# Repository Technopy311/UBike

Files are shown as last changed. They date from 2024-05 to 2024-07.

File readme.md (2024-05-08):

# UBike IWG101 Project

## Brief description

This project created for Introduction to Engineering (IWG101), consists in the research and consequently development 
of an automated bicycle holder, this with the purpose of optimizing the saving process of a bicycle in the university.

## Technologies involved

### Software

Web:
- Django Framework (Backend)
- Bootstrap Library (Frontend)

Hardware:
- ESP32 C++/Arduino custom code.

### Hardware

- ESP32 Dev Kit 1, as microcontroller.
- RFID reader module (RC522).
- Red LED.
- Custom primary security system.
- Relay.
- Solenoid.

### Primary security system
Each module will have a security system, wich will activate in cases such:
- Improper module handling.
- Energy outage.
- Robbery attempt.

Under this events, this system will become active, this prevents the unlocking of the solenoide, unless a designated manager solves the conflict or issue

## Working process:
- A series of modules will be available, each one in a parking site.
- All the modules will connect through WiFi, to a centralized server, which will be in charge of managing the authentication, permissions, registering, among others.
- The authentication will be made through the Unique ID of each keychain (provided to each user, per bicycle).
- Once authenticated (and server-side confirmed), the solenoid will contract for a few seconds, allowing the user to save the bicycle.
- It is necessary perform the authentication to either save or take out the bicycle, this with the objective to improve security and backup records.
- The LED will indicate through blinking, the status of the solenoid.

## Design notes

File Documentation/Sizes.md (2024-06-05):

# Device sizes
## ESP32 Dev-Kit
54.6mm x 27.49mm
## RC522 (RFID reader)
59.5mm x 39mm
## Step-Down module
48.5mm x 23mm
## Relay coil
40mm x 15mm x 20mm
## Case
120mm x 77mm x 37mm

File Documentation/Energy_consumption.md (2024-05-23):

# uBike module power consumption
## Power Supply
To provide electricity to every module, we are currently using a Huawei branded Modem power supply, which suplies 12 volts at 1.5 amperes (maximum 18 watt per hour)

The current must be divided in 2 ways, one will pass through a Step-Down module (LM2596) to lower the voltage that will reach the central module, the other shall get cut at the Relay module, which will only keep that current going when the central module send the signal to the relay module.
## ESP32 Energy consumption and power output
The ESP32 DevKit ofers up to 3.3 volts at 40 mAmps (20 recomended) per gpio Pin
## Energy consumption sheet
- Led (Single) = 47 mAmps at 3.3 volts (Without resistor) = 150 mOhms
- RGB Led (White) = 80 mApms divided in 3 pins at 3.3 volts
- RGB Led (White, 16 ohm Resistor added) = 30 mAmps divided in 3 pins at 3.3 volts
- Buzzer = 15 mApms at 3.3 volts = 50 mOhms
- RC522 = 6 mAmps at 3.3 volts (On standby)
- Relay = 1.5 mAmp at 3.3 volt (On standby)
## Single Module consumption
A single module in neutral state (Waiting for a keychain) needs at least 200 mAmps to work correctly.
## Solenoid device consumption
The device that is used to lock the bikes uses almost the whole capacity of the power supply, hence, the resistance of the solenoid is 8 ohms, because of that, the circuit board of the module must contain electrolytic Capacitors, to hold the power while the solenoid circuit is closed.
- The solenoid doesn't need to be powered for more than half a second, that time is just enough to unlock the bike.

## Conclusion
The power supply we are currently using is enough to power multiple modules at once, however we will focus in make a single one working from it.

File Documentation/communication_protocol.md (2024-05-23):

# Communication Protocol between Server and ESP32 module

## Description
This document describes verbally how is established the communication 
through HTTP between the main Server and the ESP32 module, how it behaves
and the primitive protocol that has been created to allow this nexus.

### The concept

In first place, it is necessary to have in mind that this protocol has been
designed for a simple thing as objective, and it is to:

<ol> 
    <li>Allow the ESP32 module send the authentication data it gathers from the User's physical RFID Keychain, identify itself, and get the response back from the server.</li>
    <li>Allow the server tell the ESP32 if it needs to open a slot to permit the saving or remotion of bicycles if needed or pertinent.</li>
</ol>

Issues related to security will not be addressed by now, since it has been left for the last stage of the project, and could even not be included for the final delivery.

### First part: From ESP32 to the Server.

In this project, we have got to the necessity of identifying each user, so that way we can keep 
track of his bicycle and know his identity.

For such, we have decided to utilize a simple RFID Keychain. 
Why RFID? because it is very easy to implement this protocol in the ESP32 and other boards, through the use of libraries. 

In this consists the first step of the communication: Reading the Unique Identifier of the user's Keychain.
After performing such read, we save the value of it.

Now comes the second step, sending the data, to accomplish it, we first have to connect the board to Wifi, but that item is not covered in this documment; going forward and assuming Wifi connection, the board proceeds to create an HTTP POST request, an HTTP request is a petition to a web server, just like when a normal everyday user surfs the net, whenever this user wants to access a page (by clicking a link for example), the computer has to perform a request. The usual request, is to get something from the web server, and this kind of request is known as a GET request, but in this case, it is necessary to send data to the server, that is why the ESP32 has to perform a POST request. The HTTP communication is performed by already available libraries. 

For the POST request, there are a few things needed:
- URL: The "link" of the web server.
- UUID: The Unique Identifier of the Keychain.
- IP Address of the board.

This three elements allow us to start a connection to the server, by sending this data in a JSON format arbitrary set up by us (the developers). JSON you may ask, is a text format, which makes easy to standarize the access to information, you may think of it as a standard which allows you to say "Hey, I want the data to be in this order, and so on"

In this case, the JSON data we send, looks like this:
```{ "uuid": UUID OF THE KEYCHAIN, "ip": IP ADDRESS OF THE BOARD}```

That way, when receiving the data in the server, the server can inmediatly check the data with the name 'uuid' and 'ip', and access such elements.

### Second part: In the Server.

Assuming the request sent from the board has succesfully arrived at the web server, the server can now do things with this request, for the project's purposes, it is first mandatory to check if the data is the right data.

For this, we first make sure that the request is a POST request, if it isn't, we throw it away.
Then, we make sure that the JSON data (as show before) exists, and has the information we need, else we throw it away.

After this, we can perform a second step, the most important one, use the data!

#### Using the data

The flow is as follows:

<ol>
    <li>Check if the UUID is an integer value.</li>
    <li>Get the Keychain with such UUID from the Database (DB).</li>
    <li>Get the ESP32 module with the same IP Address from the DB.</li>
    <li>Access the Bicycle Holder associated with the ESP32 module.</li>
    <li>Access the user related to the Keychain.</li>
    <li>Try to get the user's Bicycle.</li>
    <li>Check if the Bicycle is in the Bicycle Holder.</li>
    <li>If the Bicycle is not in the Holder, check if its in another holder.</li>
    <li>If the Bicycle is not in another holder, add it to the Bicycle holder</li>
    <li>If the Bicycle is in the holder, then remove it from it.</li>
</ol>

Each time any step in this sequence fails, the server sends a response to the ESP32 telling it that it
failed... Well... almost.

In the steps 8, 9 and 10, the server sends some special responses to the board, allowing it to know that this
special cases have ocurred.

### Second part, part 2?: From the Server to the ESP32:

Keeping with the idea of the special cases, we have aggreed to create a special language to communicate and let know the board what has happened.

Since this is programming, we have chosen to use a tuple to make easier this task, it is like this "(elem1, elem2, elem3, ..., elemN)"

Why? Because once created you can't change them, this prevents from errors happening while the server is running; and because it is intuitive the way to access the data in them, like a list. For more details, use google.

The format for the tuple we use, is like so: ```(code, index_slot)```

The code, is the element which allows the board to know what situation has happened; and the index_slot is the number of slot that the ESP32 has to open.

This are the situations that could happen, and the tuple created for the case:

- Bicycle is in another holder: ("-1", None)
- Bicycle added to holder: ("0.1", slot_position)
- Bicycle is not a real bicycle: ("0.2", None)
- There is no empty place: ("0.3", None)
- Bicycle removed from holder: ("1.1", slot_position)
- Bicycle not in holder: ("1.2", None)

After this, we take the tuple data, and we give it to a JSON object which looks like so:
```
    {
      "code": controller_data[0],
      "slot_to_open": controller_data[1]
    }
```

In the "code" part, we put the first item of the tuple, and in the "slot_to_open" we put the second item of the tuple.

Then we send an HTTP response to the ESP32 Board, with the data, and a HTTP status code of 200, which lets know the ESP32 know that the connection has been successful.

### Third and last part: Back in the ESP32.

This element has not yet coded, but it is very trivial, something to be done after finishing tests in the communication, to make sure it works smoothly, fast and very robust.

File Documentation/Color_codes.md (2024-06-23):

# Color codes for each case
- Neutral (Free) :  
    >Green: #00FF00 HEX or (0,1,0) RGB
- Neutral (Ocupied) : 
    >Blue: #FFFFFF HEX or (0,0,1) RGB
- Reading / Processing : 
    >Cyan: #00FFFF HEX or (0,1,1) RGB
- Process error or invalid RFID tag : 
    >Magenta: #FF00FF HEX or (1,0,1) RGB
- Wrong parking : 
    >Yellow: #FFFF00 HEX or (1,1,0) RGB
- Accepted / Authenticated / Starting machine :  
    >White: #FFFFFF HEX or (1,1,1) RGB
- Emergency mode / Error in the machine : 
    >Red: #FF0000 HEX or (1,0,0) RGB

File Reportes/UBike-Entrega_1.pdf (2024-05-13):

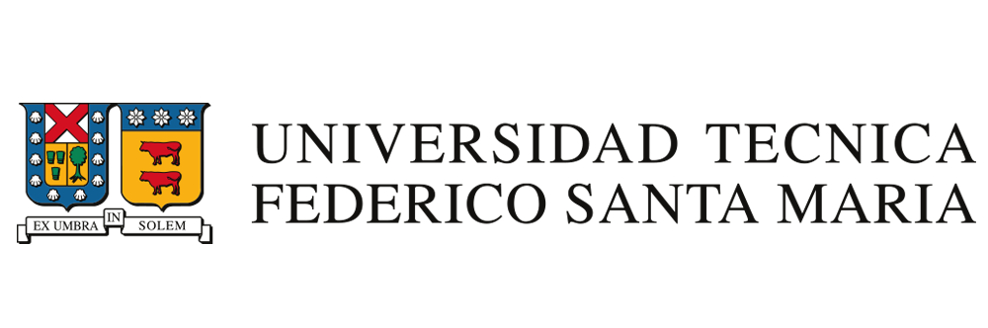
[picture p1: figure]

IWG101: Introduccion A La Ingenier ´ | ía

## Primera Entrega Proyecto UBike - Introducción a la Ingeniería

Estudiantes: | Sebastián Saldías - Acza Riffo - María Poblete - Josué Leiva
Profesor: | Luis Lizama
Ayudante: | Andrés Pino
Fecha: | 08 de Mayo, 2024

## Contents

1 Resumen | 2
2 Introducción | 2
3 Desarrollo | 2
4 Diagramas | 4
5 Conclusiones | 7
6 Referencias | 7

IWG101 Introducción a La Ingeniería | 2024

## 1 Resumen

En esta entrega del proyecto UBike —University Bike—, se presentarán diversos aspectos, se detallará la problemática que solucionaremos y por sobre todo se ahondará en el método de solución que estamos utilizando. Junto a esto se presenta un poco de la planificación y las tareas que estamos próximas a completar. Complementamos esta información con algunos diagramas que ilustran los procesos más técnicos.

## 2 Introducción

En esta primera entrega, se abordarán diversas problemáticas con respecto al proyecto llamado UBike. Se tratarán elementos tales como la planificación del proyecto, sus áreas, y el método de solución de la problemática. Esto además de presentar los avances ya existentes, en progreso y por realizar; incluída una calendarización con fechas estimadas.
Recordando un poco, se tiene que el problema a analizar, e idealmente resolver de manera inicial, trata (en pocas palabras) de abordar el dilema de la inseguridad e ineficiencia en cuanto al uso de los bicicleteros en las instalaciones de la universidad.

## 3 Desarrollo

### 3.1 Método de Resolución

Para resolver este problema, junto al equipo, se pensó en crear un sistema que permita al estudiantado utilizar algún medio de autenticación para así poder ingresar y en su defecto, retirar, la bicicleta que el mismo utilice en la USM.
Abordando la idea, se ideó utilizar alguna tarjeta o llavero con tecnología RFID para la autenticación y algún tipo de módulo que permita leer este objeto, y que pueda enviar esta información a algún servidor para ser procesada. Este dicho módulo, se encontraría en cada bicicletero, permitiendo así que cada uno de estos, fuese independiente de otro, tanto en energía como en libertad de locación.
Luego de discutirlo, se decidió proseguir de la siguiente manera: Utilizar un microcontrolador Raspberry Pi Pico W [1] como dispositivo central del módulo, una tarjeta lectora de RFID [2] modelo RC522 [3] la cual se conectaría a este microcontrolador, un diodo LED de color rojo para efectos de indicar el funcionamiento del módulo. Se escogió utilizar este microcontrolador inicialmente, ya que permite conectividad Wifi y Bluetooth, lo que nos otorga flexibilidad para desarrollar esta solución.
La tarjeta lectora se conectaría a este microcontrolador, al igual que el LED, mediante cables, hacia los puertos GPIO [4] de este. Este microcontrolador permite ser programado oficialmente mediante el soporte de micropython entregado por Raspberry Pi Foundation, o mediante un SDK de C/C++ también soportado por la misma institución [5], para mayor facilidad se optó por el uso de micropython para programar el dispositivo.
Para poder procesar los datos y realizar procesos más exigentes, además de favorecer la escalabilidad, se decidió por establecer un servidor centralizado, en donde cada módulo (por cada bicicletero) se conecte mediante Wifi a este servidor, y pudiesen comunicarse para que así cada módulo pueda enviar el Unique ID (UID) de cada llavero o tarjeta (dato leído por la tarjeta RFID), hacia este servidor.
Con el fin de crear este servidor, se decidió desarrollar una página web mediante el robusto framework Django [6] de desarrollo backend, esto permite crear un backend robusto y rápido, fácilmente desplegable, además de seguro. Al tratarse de una plataforma web, se facilita tanto la comunicación módulo-servidor mediante la creación de APIs, como el acceso del usuario a la solución que se está planteando mediante una interfaz web.
Django es útil como solución backend, pero es necesario también una solución frontend, por simplicidad y agilidad, se utilizará la famosa librería de desarrollo BootStrap [7] la cual permite el desarrollo responsive de páginas web.
Antes de continuar, se presenta un diagrama esencial el cual tiene como finalidad sintetizar las ideas de este proyecto. No tiene como aspecto principal lograr precisión técnica, sino ilustrar un inicio del proyecto.
USM 2024 - 2 | 2

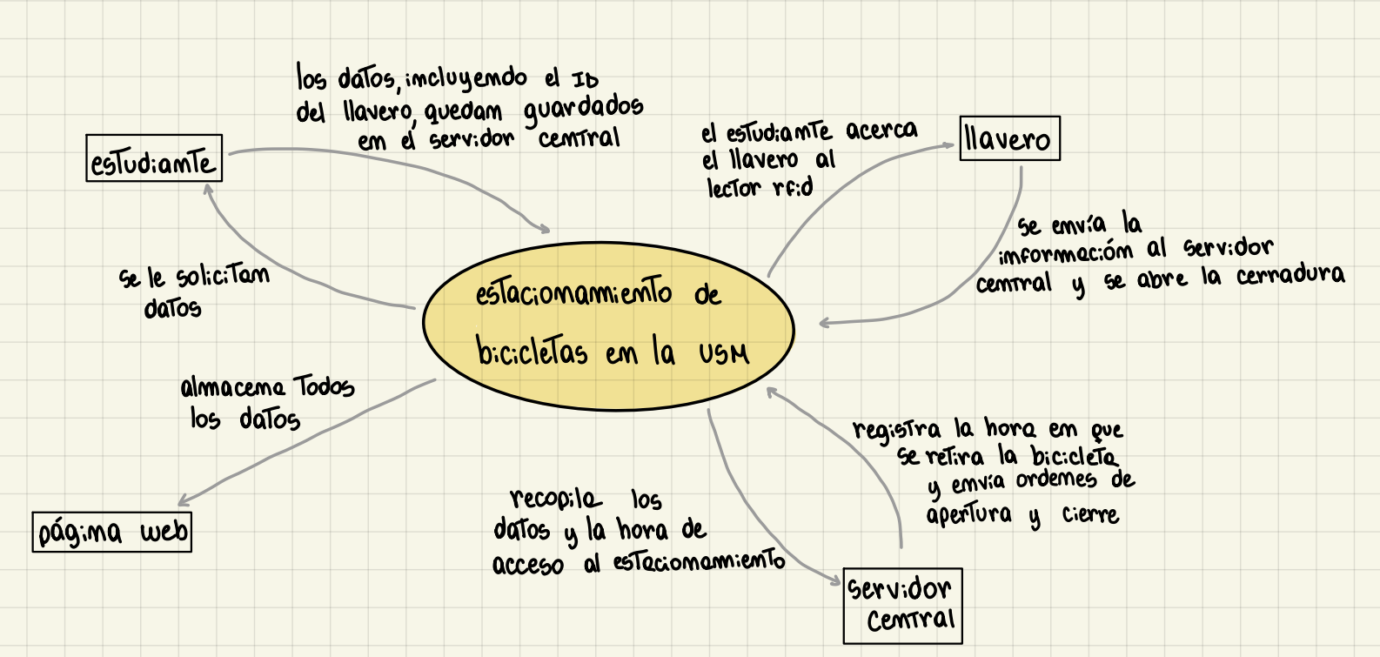
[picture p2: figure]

Figura. 1: Diagrama esencial del proyecto.

### 3.2 Cambios en el método

Lo visto en el ítem anterior es un desarrollo de la idea inicial, pero en vista del rápido avance necesario para cumplir con los plazos (más información posteriormente), este desarollo afectó a algunos cambios. El más notorio de estos, el cambio de microcontrolador.
Anteriormente se propuso utilizar el microcontrolador Raspberry Pi Pico W, pero se encontraron algunas limitaciones en el uso de este, algunas de estas siendo:
- Lentitud de ejecución de código.
- Falta de documentación robusta (micropython y SDK C/C++).
- Poca madurez en el desarrollo con micropython.

Para enfrentar este problema, se decidió cambiar el microcontrolador, esta vez utilizando la famosa placa de la compañía Espressif, en particular se trata de una ESP32 DevKit v1. [8] (o también llamado DevKitC).
Este microcontrolador es altamente utilizado en la industria, es robusto y tiene alta compatibilidad con diversidad de sistemas, librerias, protocolos, etc. También posee conectividad Wifi y Bluetooth, permitiendo al proyecto no desviar su curso en cuanto al desarrollo de software se trata, con una pequeña excepción.
Esta placa, se desarrolla utilizando C++, tal y como Espressif lo indica en su documentación [8], pero también se puede programar utilizando el famoso IDE de Arduino [9], lo cual facilita la tarea.
Cabe destacar que todo el avance, en cuanto a software se trata, se encuentra disponible en el repositorio de GitHub del proyecto UBike [10].

### 3.3 Planificación

Con el propósito de facilitar el avance, el proyecto se ha dividido en diversas áreas, en donde cada uno de los estudiantes del grupo trabaja, aprende y se especializa, esta son:

- Desarrollo Frontend (María Poblete, Acza Riffo)
- Modelación 3D (Sebastián Saldías)
- Electrónica (Sebastián Saldías)
- Desarrollo Embebido (Josué Leiva)
- Desarrollo Backend (Josué Leiva)

Como plataforma de organización en cuanto a tareas, avances y fechas se trata, se utiliza Microsoft Planner [11], una aplicación que permite el ordenamiento de los proyectos mediante la metodología Kanban.

Debido a la complejidad de la planificación, y a las limitaciones de la plataforma, en caso de desear obtener acceso a esta, favor enviar un correo solicitando este acceso a la siguiente dirección: jleivap@usm.cl. El equipo se reserva el derecho y libertad de autorizar a quien considere competente, el acceso a la plataforma.
A modo de resumen se pueden mencionar las siguientes tareas por realizar o completar:
- Entrega Nro. 1.
- Definir fuente de poder para prototipo.
- Definir material y diseño para soporte prototipo de bicicletas.
- Crear vistas de usuario (registro y común) (frontend).
- Crear vista para guardias (frontend).
- Implementar apertura de solenoide según Response de API.
- Realizar diagrama de cascada de los puntos críticos del proyecto.

Si bien existen más tareas por mencionar, se recalca nuevamente el uso de la plataforma Ms. Planner.

## 4 Diagramas

En este proyecto de alta complejidad, teniendo en cuenta de que se trata de un ramo de primer semestre, se destaca la importancia de entender conceptualmente el funcionamiento de la solución a desarrollar. En este punto es útil el uso y creación de diagramas de flujo, es por ello que se facilitan dos diagramas en particular, un primer diagrama de flujo que indica la lógica de funcionamiento del sistema, y un segundo diagrama que muestra el proceso de comunicación entre el módulo bicicletero y la API del servidor, esto mediante el protocolo HTTP y el uso de Wifi; figuras 2 y 3 respectivamente.

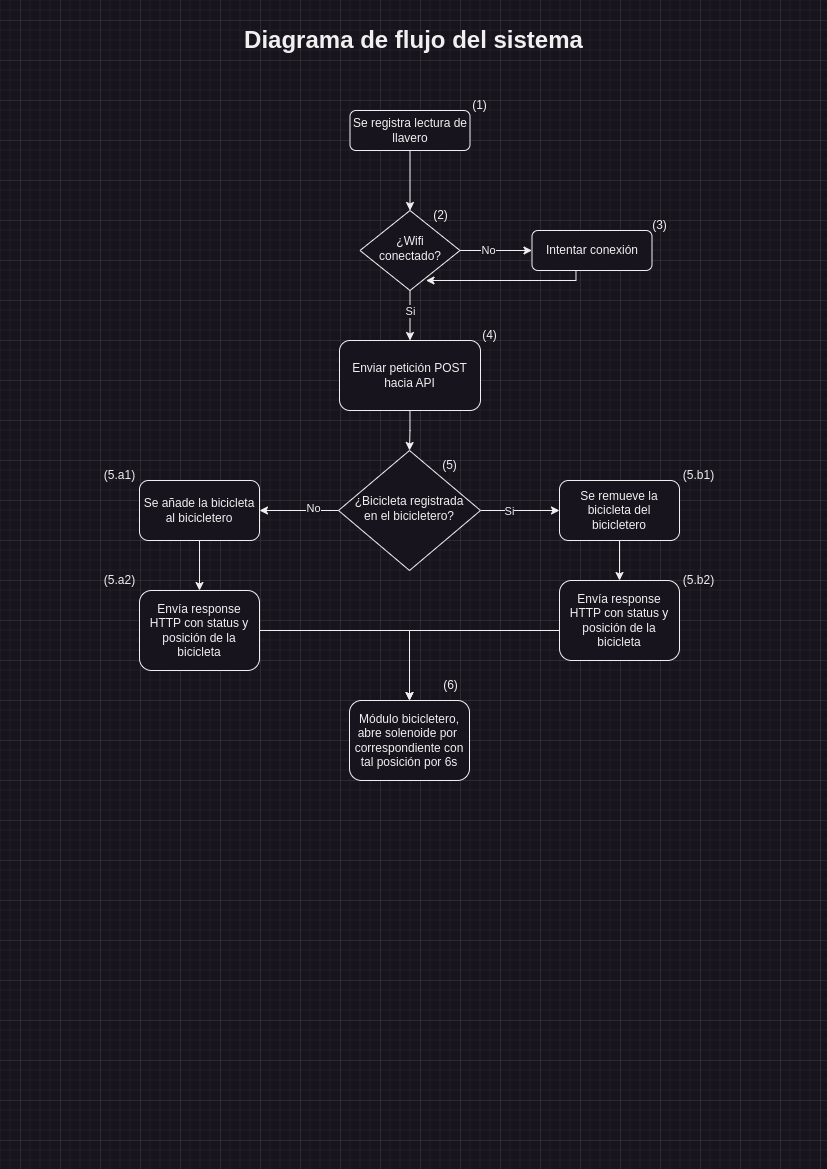
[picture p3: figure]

Figura. 2: Diagrama de flujo de lógica del funcionamiento.

Este diagrama de flujo, representa la lógica que nuestra solución plantea, brindando así una clara referencia con respecto a los objetivos que cada pieza de nuestro planteamiento, debe lograr.
El evento principal, el cual gatilla la lógica descrita, es la lectura del llavero del usuario, mediante el lector RFID ya mencionado anteriormente; y termina cuando el módulo finaliza la conexión con el servidor central y actua con respecto a la respuesta de este.

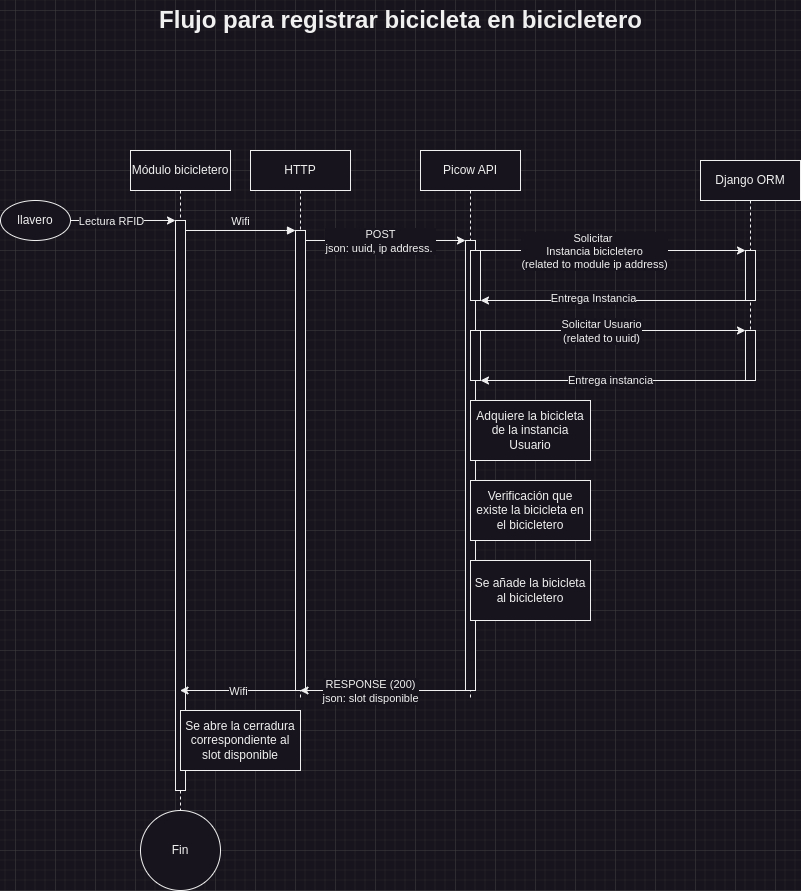
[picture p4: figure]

Figura. 3: Flujo de comunicación entre módulo bicicletero y servidor.

Esta última figura (diagrama de cascada), muestra el proceso de comunicación entre el módulo bicicletero y el servidor central, mediante el protocolo HTTP, utilizando WiFi de por medio.
A medida que avanza el proyecto, estas estructuras pueden variar, por lo que estos diagramas no son definitivos. Para esta entrega estos elementos sólo tienen la finalidad de ilustrar al lector cómo se está desarrollando esta solución.

### 4.0.1 Nota

Cabe destacar que hemos decidido no incluir en esta entrega algunos otros detalles de la solución. Entre estos elementos se incluyen: Método de seguridad primaria, planificación respecto al frontend y la lógica del sistema cuando ocurren excepciones en el funcionamiento de los distintos puntos críticos de la infraestructura digital que se está desarrollando.
Esto se ha decidido así, ya que creemos fundamental sentar bases robustas dentro del proyecto, para así no tener mayores problemas más adelante en el transcurso del desarrollo.

## 5 Conclusiones

Luego de presentar esta información, concluimos como equipo, en que es imperativo trabajar activamente entre integrantes, compartiendo información con las otras áreas, para así mantener un trabajo uniforme, que logre mantener la visión y objetivo de la solución a implementar.
Además de esto, reconocemos la necesidad de mantener una organización y estructuras claras, creando objetivos tanto a corto como a largo plazo, logrando así los avances necesarios para evitar retrasos.

## 6 Referencias

[1] R. P. Foundation, “Raspberry pi pico,” Disponible en https://www.raspberrypi.com/products/raspberry-pi-pico/.
[2] B. Fennani, H. Hamam, and A. O. Dahmane, “Rfid overview,” in ICM 2011 Proceeding, 2011, pp. 1–5.
[3] NXP, | “Mfrc522 | standard | performance | mifare | and | ntag | frontend,” | Disponible | en
https://www.nxp.com/docs/en/data-sheet/MFRC522.pdf (2024/04/4).
[4] R. | P. | Foundation, | “Physical | computing | with | python,” | Disponible | en
https://projects.raspberrypi.org/en/projects/physical-computing/1.
[5] ——, “Software development,” Disponible en (https://www.raspberrypi.com/documentation/microcontrollers/raspberrypi-pico.html#software-development).
[6] D. S. Foundation, “Django, the web framework for perfectionists with deadlines.” Disponible en https://www.djangoproject.com/.
[7] B. Team, “Build fast, responsive sites with bootstrap,” Disponible en https://getbootstrap.com/.
[8] E. Systems, “Esp32-devkitc.”
[9] Arduino, “Arduino ide 2.3.2,” Disponible en https://www.arduino.cc/en/software (20/02/2024).
[10] J. Leiva and S. Saldías, “Ubike iwg101 project,” Disponible en https://github.com/Technopy311/UBike.
[11] M. Office, “Microsoft office,” Disponible en https://tasks.office.com/.

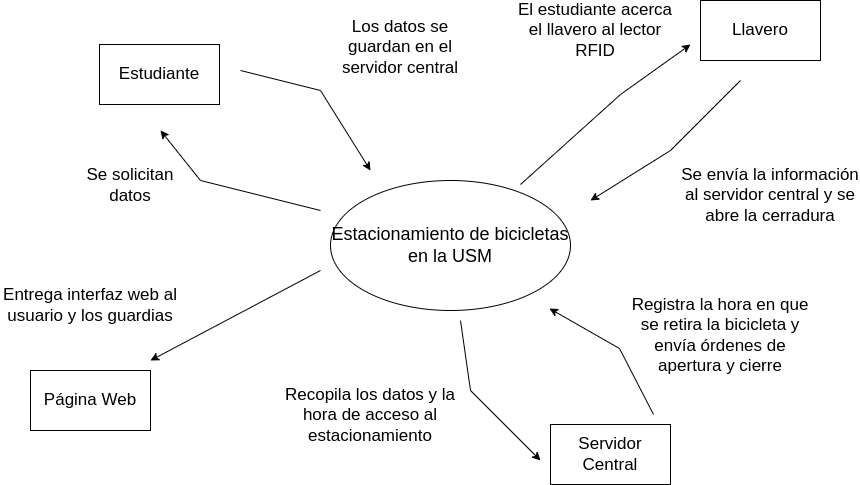
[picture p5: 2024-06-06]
Charts/Diagrama esencial.drawio.png

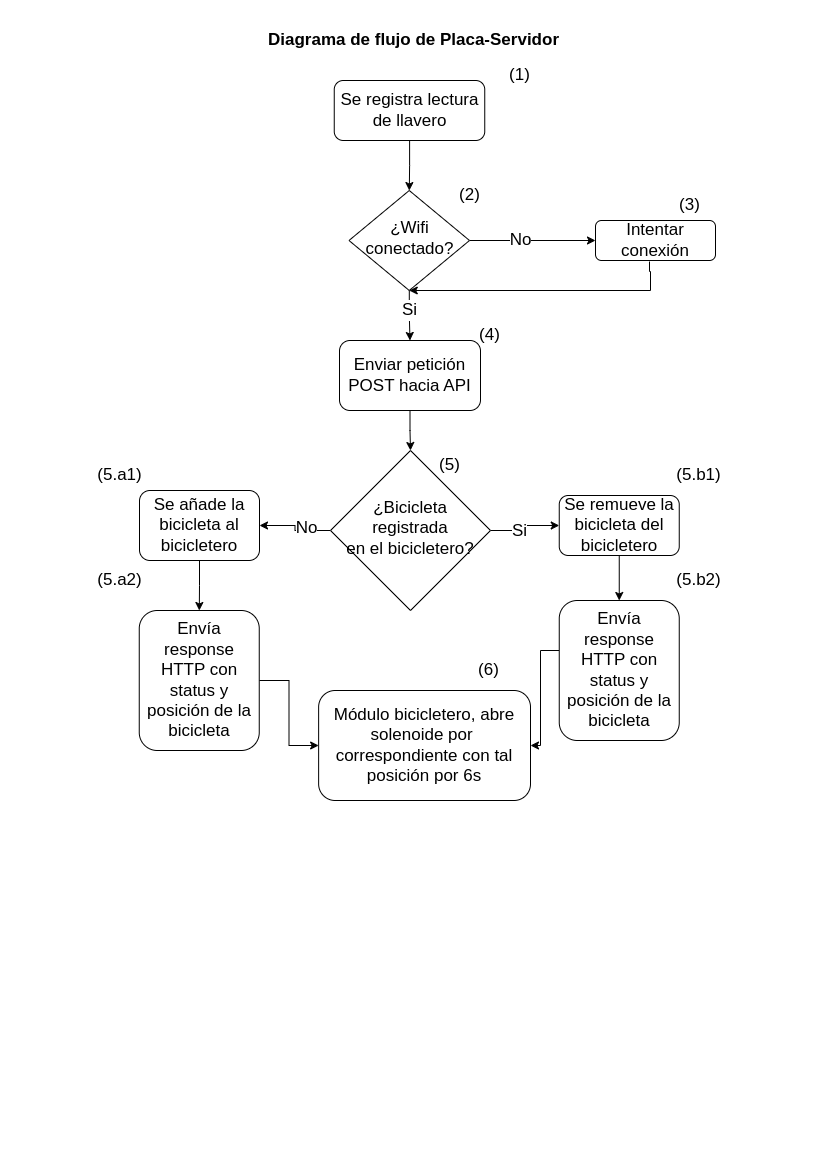
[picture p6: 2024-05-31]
Charts/System Flow Chart.drawio.png

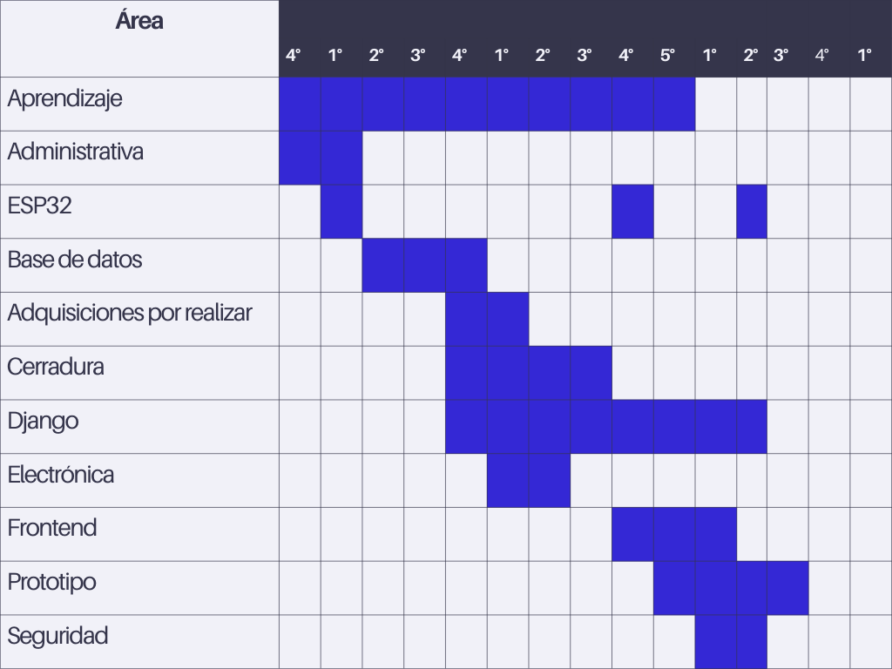
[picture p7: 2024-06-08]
Charts/Carta Gantt Entrega 2 .png

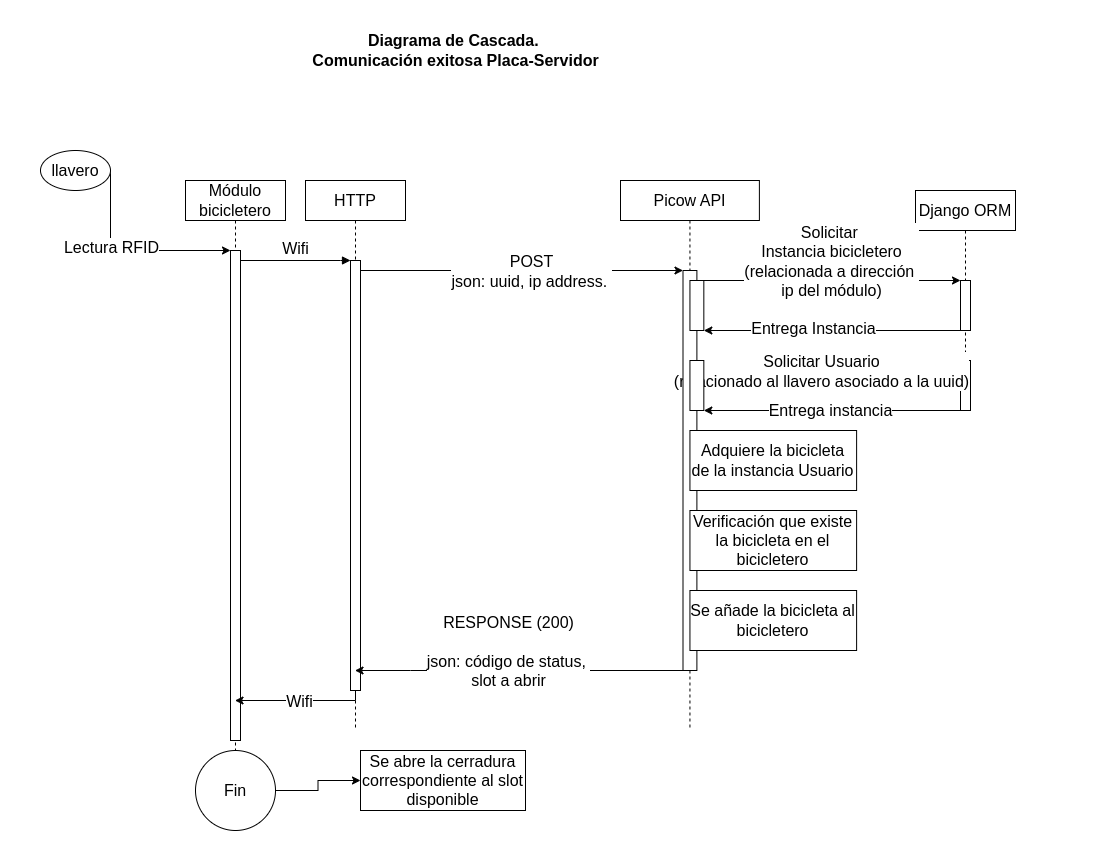
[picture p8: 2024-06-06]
Charts/communication chart.drawio.png

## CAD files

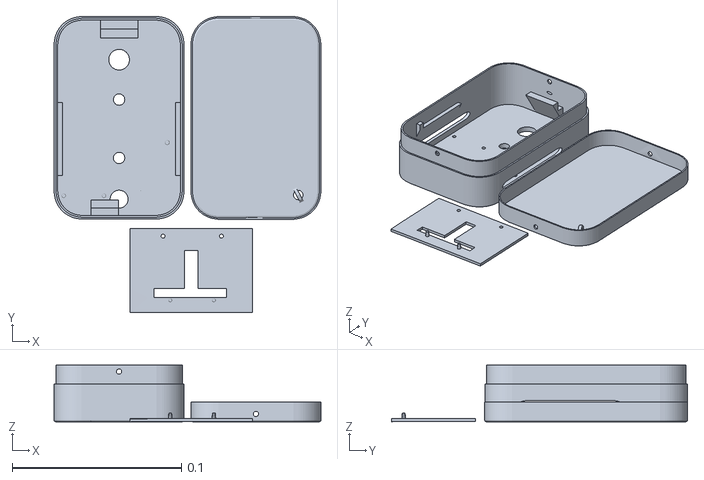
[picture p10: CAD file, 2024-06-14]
Modelo 3D/espcasev6.stl
0.158 x 0.175 x 0.0334

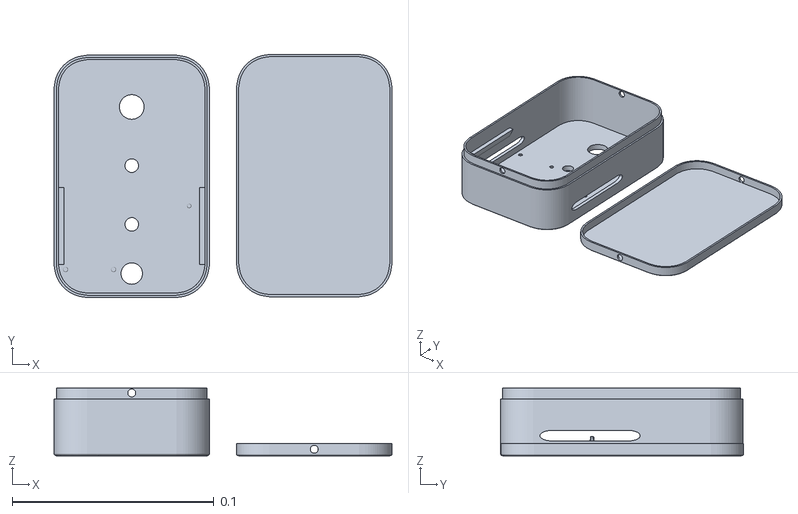
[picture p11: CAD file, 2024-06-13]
Modelo 3D/espcasev5.stl
0.167 x 0.12 x 0.0334

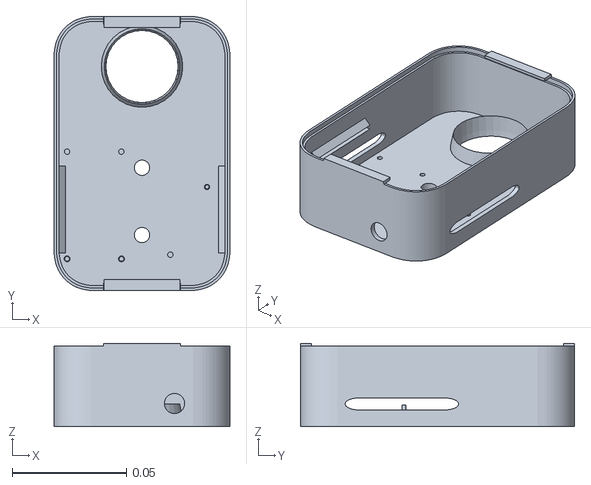
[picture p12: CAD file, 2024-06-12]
Modelo 3D/espcasev4.stl
0.077 x 0.12 x 0.0365

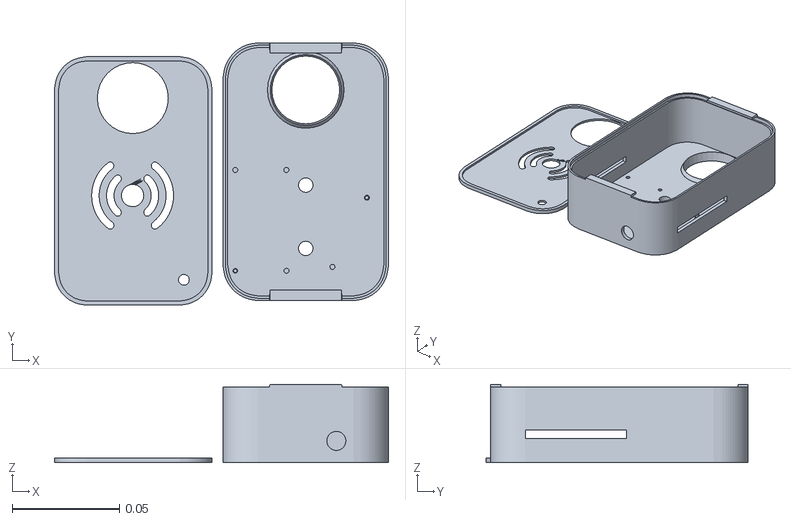
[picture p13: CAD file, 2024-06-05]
Modelo 3D/espcasev3.stl
0.155 x 0.122 x 0.0365

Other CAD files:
Modelo 3D/espcasev1.blend
Modelo 3D/espcasev2.blend
Modelo 3D/espcasev3.blend
Modelo 3D/espcasev4.blend
Modelo 3D/espcasev5.blend
Modelo 3D/espcasev6.blend

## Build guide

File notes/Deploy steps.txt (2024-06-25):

- Clone Repo
- Crear virtualenviroment (virtualenv)
- Install requirements
- Install nginx
- Add "client_max_body_size 100M;" to nginx.conf in http
- Setup services (in conf folder)
- Setup .env file (MAIN_ADDR, SECRET_KEY)
- Setup static_root
- Setup nginx folder at /var/www/static_root
- Run collectstatic
- Copy static_root to /var/www/static_root
- Make sure media folder exists, else, create it (ProyectoMarraqueta)
- Debug = False
- Start gunicorn and nginx services

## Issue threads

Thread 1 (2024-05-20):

Bicycle holder track not persistant

Technopy311, 2024-05-20:
The current desing of the BicycleHolder model (core/models.py), keeps track of the bicycles by using an array.

This approach, even though it works, has a major flaw; In case of shuting down the server, or having it to reset or reboot, the array inside the bicycle holder's intances, reset, hence losing all the track of bicycles in each bicycle holder.

Technopy311, 2024-05-20:
Created branch iss#01, to assert this major flaw.

Closed 2024-05-21.

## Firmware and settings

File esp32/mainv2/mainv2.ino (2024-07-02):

#include "mainv2.h"
#include "buzzrgb.h"

char* ssid = "dd-wrt";
char* password = "5iMLKcnkLk2MGc";
char* server_url = "http://192.168.1.102/api/recv";


MFRC522 mfrc522(SS_PIN, RST_PIN);

bool connectToWiFi() {
  Serial.println("Connecting to WiFi...");
  WiFi.begin(ssid, password);
  int attempts = 0;
  while (WiFi.status() != WL_CONNECTED && attempts < 10) {
    delay(750);
    Serial.println("Retrying...");
    attempts++;
  }
  if (WiFi.status() == WL_CONNECTED) {
    Serial.println("WiFi connected");
    return true;
  } else {
    Serial.println("Failed to connect to WiFi");
    return false;
  }
}


void controller(const String& code, int slot_position){
  if (code == "0.1"){ // Code to add bicycle to holder
    rgb_set(1, 1, 1); // Set LED color to White
    success_buzzer_sound();
  } else if (code == "1.1"){ // Code to remove bicycle from holder
    rgb_set(1, 1, 1); // Set LED color to White
    success_2_buzzer_sound();
  } else{
    Serial.print("No bicycle change.\n");
    rgb_set(1, 1, 0); // Set LED color to Yellow
    error_buzzer_sound();
  }
  delay(1000); // Short delay after output message or action
}

bool sendUUID(const String& uuid, const String& ip) {
  Serial.println("Sending UUID to server...");
  Serial.print("UUID: ");
  Serial.println(uuid);
  JSONVar dataObject;
  dataObject["uuid"] = uuid;
  dataObject["ip"] = ip;
  String jsonString = JSON.stringify(dataObject);
  HTTPClient http;
  http.begin(server_url);
  http.addHeader("Content-Type", "application/json");
  int httpResponseCode = http.POST(jsonString);
  String response_data = http.getString();
  http.end();

  JSONVar response_data_json = JSON.parse(response_data);

  controller(response_data_json["code"], response_data_json["slot_to_open"]);

  if (httpResponseCode == HTTP_CODE_OK) {
    Serial.println("UUID sent successfully");
    return true;
  } 
  Serial.print("HTTP Error code: ");
  Serial.println(httpResponseCode);
  return false;
}

String readRFID() {
  if (!mfrc522.PICC_IsNewCardPresent()) {
    return "";
  }
  if (!mfrc522.PICC_ReadCardSerial()) {
    return "";
  }
  String uuid = "";
  for (byte i = 0; i < mfrc522.uid.size; i++) {
    uuid += String(mfrc522.uid.uidByte[i] < 0x10 ? "0" : "");
    uuid += String(mfrc522.uid.uidByte[i], HEX);
  }
  mfrc522.PICC_HaltA();
  return uuid;
}

void setup() {
  Serial.begin(115200);
  init_periferals();
  SPI.begin();
  mfrc522.PCD_Init(); // Init mfcr522
  pinMode(LID_CHECK, INPUT);
  while (!Serial) {}
  
  connectToWiFi();
  Serial.println(WiFi.localIP().toString());
  rgb_set(0, 1, 0);
  emit_sound(10, 3); 
}

void loop() {
  if (WiFi.status() != WL_CONNECTED) {
    rgb_set(1, 0, 0);
    connectToWiFi();
  }
  // Check if lid is open
  //if (digitalRead(LID_CHECK)!=1){
    //MACHINE EMERGENCY
  //}
  else{
    rgb_set(0, 1, 0);
    String uuid = readRFID();
    if (uuid != "") {
      rgb_set(0, 1, 1);
      String ip = WiFi.localIP().toString();
      if (sendUUID(uuid, ip)) {
        delay(200); // Delay to avoid sending data too frequently
      }
      delay(20); // Delay between RFID scans
    }
  }
}

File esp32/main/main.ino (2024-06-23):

#include <WiFi.h>
#include <HTTPClient.h>
#include <Arduino_JSON.h>
#include <SPI.h>
#include <MFRC522.h>

#define RST_PIN  0
#define SS_PIN 21 // GPIO 21 ESP32

#define HOLDER_CAPACITY 4

#define SOLENOID_OPEN_TIME 500 // In milliseconds

const char* ssid = "FPWOM";
const char* password = "NHl7g371#0";
const char* server_url = "http://192.168.100.18:8080/api/recv";

// Associate a solenoid with a pin, this is made to make programming less prone to errors
const short int solenoid_1 = 27;
const short int solenoid_2 = 26;
const short int solenoid_3 = 25;
const short int solenoid_4 = 33;

unsigned short int solenoids[HOLDER_CAPACITY] = {solenoid_1, solenoid_2, solenoid_3, solenoid_4}; // This array holds each solenoid's pin, ORDER MATTERS


// Set the Output peripherals GPIO pin location
const int buzzer = 0;
const int red = 0;
const int green = 0;
const int blue = 0;
const int RGBpin[3] = {red, green, blue};

const int LidCheck = 0; // Lid closure check

MFRC522 mfrc522(SS_PIN, RST_PIN);

int status = 0;
// Status codes:
// 0 : Machine starting
// 1 : Neutral (Empty)
// 2 : Neutral (Busy)
// -1 : Emergency Mode

bool connectToWiFi() {
  Serial.println("Connecting to WiFi...");
  WiFi.begin(ssid, password);
  int attempts = 0;
  while (WiFi.status() != WL_CONNECTED && attempts < 10) {
    delay(750);
    Serial.println("Retrying...");
    attempts++;
  }
  if (WiFi.status() == WL_CONNECTED) {
    Serial.println("WiFi connected");
    return true;
  } else {
    Serial.println("Failed to connect to WiFi");
    return false;
  }
}

void emit_sound(int freq, int times){ // Basic buzzer controller. freq means times per second, not sound wave frequency
  freq = 500/freq;
  for (int a = 0; a<times; a++){
    digitalWrite(buzzer, HIGH);
    delay(freq);
    digitalWrite(buzzer, LOW);
    delay(freq);
  }
}
void success_buzzer_sound(){ // Make sound a nice pleasing sound that indicates all is fine
  emit_sound(1, 1);
}

void success_2_buzzer_sound(){ // Make sound another nice pleasing sound that indicates all is fine
  emit_sound(2, 2);
}

void error_buzzer_sound(){ // Make sounde a not nice sound that indicates something is wrong
  emit_sound(4, 4);
}
void rgb_set(int R, int G, int B){ // Set the color of the RGB Led diode
  digitalWrite(RGBpin[0], R);
  digitalWrite(RGBpin[1], G);
  digitalWrite(RGBpin[2], B);
}

void open_solenoid(int slot_position){
  Serial.print("\tOpening slot: " + String(slot_position)+ "\n");
  digitalWrite(solenoids[slot_position], HIGH);
  delay(SOLENOID_OPEN_TIME);
  digitalWrite(solenoids[slot_position], LOW);
  Serial.print("\tSlot closed\n");
  }

void controller(const String& code, int slot_position){
  if (code == "0.1"){ // Code to add bicycle to holder
    status = 2;
    rgb_set(1, 1, 1); // Set LED color to White
    success_buzzer_sound();
    open_solenoid(slot_position);
  } else if (code == "1.1"){ // Code to remove bicycle from holder
    status = 1;
    rgb_set(1, 1, 1); // Set LED color to White
    success_2_buzzer_sound();
    open_solenoid(slot_position);
  } else{
    Serial.print("No bicycle change.\n");
    rgb_set(1, 1, 0); // Set LED color to Yellow
    error_buzzer_sound();
  }
  delay(500); // Short delay after output message or action
}


bool sendUUID(const String& uuid, const String& ip) {
  Serial.println("Sending UUID to server...");
  JSONVar dataObject;
  dataObject["uuid"] = uuid;
  dataObject["ip"] = ip;
  String jsonString = JSON.stringify(dataObject);
  HTTPClient http;
  http.begin(server_url);
  http.addHeader("Content-Type", "application/json");
  int httpResponseCode = http.POST(jsonString);
  String response_data = http.getString();
  http.end();

  JSONVar response_data_json = JSON.parse(response_data);

  controller(response_data_json["code"], response_data_json["slot_to_open"]);

  if (httpResponseCode == HTTP_CODE_OK) {
    Serial.println("UUID sent successfully");
    return true;
  } else {
    Serial.print("Failed to send UUID. Error code: ");
    Serial.println(httpResponseCode);
    return false;
  }
}

String readRFID() {
  if (!mfrc522.PICC_IsNewCardPresent()) {
    return "";
  }
  if (!mfrc522.PICC_ReadCardSerial()) {
    return "";
  }
  String uuid = "";
  for (byte i = 0; i < mfrc522.uid.size; i++) {
    uuid += String(mfrc522.uid.uidByte[i] < 0x10 ? "0" : "");
    uuid += String(mfrc522.uid.uidByte[i], HEX);
  }
  mfrc522.PICC_HaltA();
  return uuid;
}

void setup() {
  Serial.begin(115200);
  SPI.begin();
  mfrc522.PCD_Init();
  pinMode(buzzer, OUTPUT);
  pinMode(LidCheck, INPUT);
  while (!Serial) {}
  for(int i=0; i<HOLDER_CAPACITY; i++){
    pinMode(solenoids[i], OUTPUT); // Set every solenoid pin as OUTPUT
  }
  for(int i=0; i<3; i++){
    pinMode(RGBpin[i], OUTPUT); // Set every LED pin as OUTPUT
  }
  rgb_set(1, 1, 1);
  emit_sound(2, 1);
  connectToWiFi();
}

void loop() {
  if (WiFi.status() != WL_CONNECTED) {
    rgb_set(1, 0, 0);
    connectToWiFi();
  }
  if (status == -1){ // Emergency mode (WIP), it must work on the program loop, because it must mantain comunication to the server
    rgb_set(1, 0, 0);
  }
  else if (status != -1){
    // Set the status LED color acording the machine status 
    if (status == 1){
      rgb_set(0, 1, 0);
    }
    else if (status == 2)
    {
      rgb_set(0, 0, 1);
    }
    if (digitalRead(LidCheck) != HIGH){ // Enters the emergency mode in case the case lid is open
      // Send status update to server
      status = -1;
    }
    else{
      String uuid = readRFID();
      if (uuid != "") {
        emit_sound(4, 1); // Short sound to notify the user that the tag has been scaned
        String ip = WiFi.localIP().toString();
        if (sendUUID(uuid, ip)) {
          delay(200); // Delay to avoid sending data too frequently
        }
      }
    }
    delay(20); // Delay between RFID scans
  }
}

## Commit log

2024-04-13 feat(BicycleHolder core.models): Add the slots
2024-04-13 feat(core.models.BicycleHolder): add the add_bicycle classmethod, to add a bicycle instance's PK in an enmpty slot (0)
2024-04-16 Archivo de protocolo
    Primer archivo para desarrollar las ideas del funcionamiento del módulo, trabajo en proceso
2024-04-22 Modifique en gran magnitud el script main.py
2024-04-25 feat(esp32): Create new esp32 base code, for further esp32 implementation
2024-04-25 chore(esp32.main): Add comments which descript the code.
2024-04-25 fix(esp32.main): Fix syntax error in line 2, replace # for //, confusion between python comment and CPP comment.
    [main.ino]
2024-04-29 Avance modelo 3D módulo
    [espcase.blend]
2024-04-30 feat: Integrate RFID sensor MFRC522 to read card/keychain's uuid and send such uuid to the api
2024-05-02 Updated 3d model
    [espcase.blend]
2024-05-04 Submited AutoCad Model
    [espcase.blend, model.dwg]
2024-05-04 Updated Models
    [model.dwg]
2024-05-05 Updated CAD Model
    [model.dwg]
2024-05-09 chore(picow_api.views): Add prints to controller view, add response status code to recv view.
2024-05-09 optimization(esp32.main): Use WiFi instead WifiMulti library; Close http request; use String ipaddr instead of unsigned long int ipaddr
2024-05-09 Create sistem flowchart in drawio
2024-05-17 Power consumption documentation
2024-05-22 chore(picow_api.views): Add simple error handling; Implement http Responses for each case (success or error)
2024-05-22 chore/perf(esp32.main): Cleanup the code and optimize a little of memory Usage
2024-05-22 tests(picow_api.tests): Write test case to check the recv view when request is not POST
2024-05-22 chore!(core.models): Remove remaining reference to self.role and self.user_type made in commit #86fd033; Add __str__ function to BicycleHolder model; Remove nearest_guard field from BicycleHolder; Sw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
2024-05-22 Fix!(picow_api.views): Add error handling in controller function; Add proper responses in recv function to communicate errors or (in case of success) send data back
2024-05-22 doc: Create an .md file to explain very easily and conceptually how the communication protocol works, between Server and ESP32
2024-05-22 fix(core.models): Fix custom save function of BicycleHolder function, ,the super().save method was at the top of the custom function, hence not saving the changes made in slots
2024-05-22 feat(devtools): Add test case to check valid request with one place, picow_api
2024-05-22 fix(core.models): Update the model through saving it, after changing the slots array in the BicycleHolder.tracker field thorugh del_bicycle and add_bicycle methods.
2024-05-22 feat(devtools): Create create_full_request helper function, to simulate real request to picow API; Add test case when a User saves a bicycle, and then another user tries to save it's own, but there i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
2024-05-22 Resumed model developing in Blender
    espcasev1 was made before the hose boolean modification
    [espcase.blend, espcasev1.blend, espcasev2.blend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]
2024-05-22 Revert "chore/perf(esp32.main): Cleanup the code and optimize a little of memory Usage"
    This reverts commit 97401bf2b506e767fb581bc0c201c54bff6a850e.
    THe need for this revert, is to come back to a working version of the code,
    since the changes made in this commit, were not developed correctly.
    [main.ino]
2024-05-23 fix(core.models): Change KeyChain uuid field to CharField. Remove prints inside BicycleHolder, leaving only the printing of the custom save function.
2024-05-23 fix(picow_api.views): Change try/except of parameters in controller function. Make prints inside controller function more descriptive.
2024-05-23 feat(picow_api_tests): Add an automated performance case to create a Module, Holder and repeat 1000 times: creating a user, creating a keychain, creating a bicycle and then add and inmediatly remove 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
2024-05-23 add csv file created by picow_api_tests stress test
    [increasing_timings.csv]
2024-05-23 Upload first version of ESP32 code, made by chatgpt based on main.ino code
2024-05-23 feat(esp32): Implement solenoid opening based on Server API response!!!
2024-05-23 chore(esp32): Setup module for simple prototype with leds.
2024-05-23 feat(picow_api.views): Allow to keep track if bicycle is in another holder than the one who sent the request.
2024-05-23 chore(esp32): Remove now unnecessary serial prints
2024-05-23 Updated models and documentation
    [espcasev2.blend, espcasev3.blend, espcasev3.stl]
2024-05-24 Fix(frontend_files): Fix text color in modals. Add margin to register button in modal
2024-05-27 Case model
    Latest revision: Device support aded
    [espcasev3.blend, espcasev3.stl]
2024-05-31 chore(esp32): Just change url and delete comment
2024-06-04 Restarted the module 3d model development
    [espcasev3.stl, espcasev4.blend]
2024-06-06 Added procesed gcode ready to be printed
    [espcasev4.blend, espcasev4.stl]
2024-06-12 Updated Case 3D Model
    [espcasev4.blend, espcasev4.stl, espcasev5.blend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]
2024-06-12 Updated 3D Model and documentation
    [espcasev5.blend, espcasev5.stl]
2024-06-13 Fifth revision of the case is now completed, proceding with the sixth
    [espcasev5.blend, espcasev5.stl, espcasev6.blend]
2024-06-14 Final revision of the 3D Model
    [espcasev6.blend, espcasev6.stl]
2024-06-14 Merged the contents of chatgpt_version.ino into main.ino (Thus, chatgpt_version.ino is now deprecated and can be deleted)
    [espcasev4.blend]
2024-06-15 feat(core.templates): Update base.html to implement dynamic logout button. Update welcome.html for user registry.
2024-06-23 Fix code (Syntax errors and variable names)
    [main.ino]
2024-06-23 fix(esp32.main.ino): add semicolon.
2024-06-23 chore(esp32.mainv2): Start to order esp32 code properly.
2024-06-25 Print useful info
2024-06-25 tune esp32 buzzer timings
    [buzzrgb.cpp]
2024-06-26 chore(core.templates): Remove unused button. Fix responsive image
2024-06-30 remove solenoid integration
2024-06-30 create dummy script for UUID esp32 reading
2024-07-01 Modify Output peripherals code and main code to fix the behaviour of the LEDs
    [buzzrgb.cpp, mainv2.ino]
